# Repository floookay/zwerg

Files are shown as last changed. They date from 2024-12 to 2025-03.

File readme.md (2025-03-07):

# zwerg

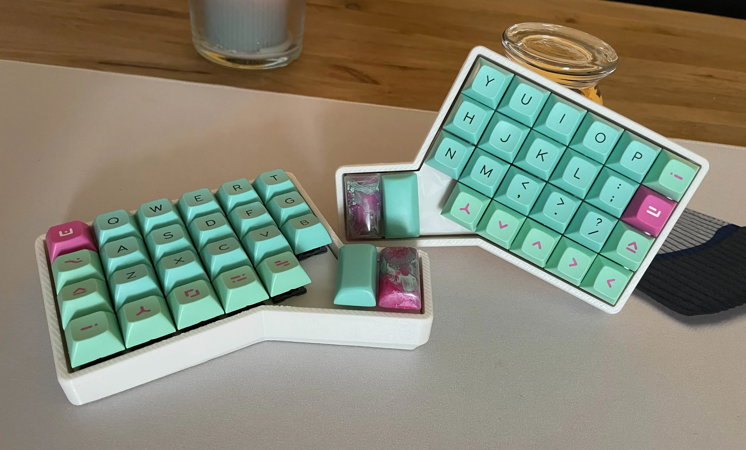
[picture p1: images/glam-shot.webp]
glam shot


The zwerg is a 3x6 (well technically 4x6 I guess?) split ortholinear 40% keyboard.
It's heavily inspired by [RGBKB.net's Sol 3](https://rgbkb.net/collections/sol-3) of which I own two and absolutely adore.

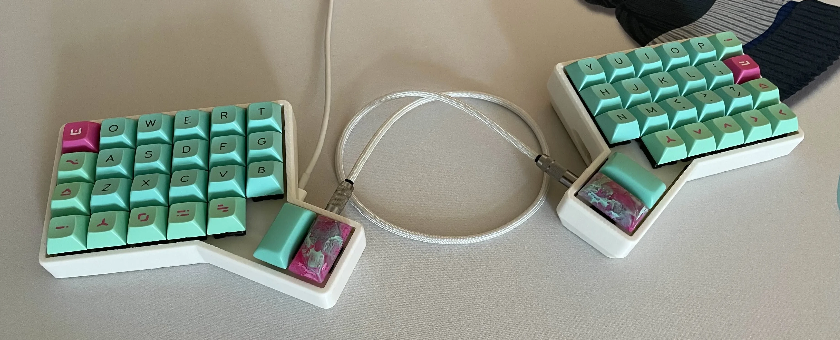
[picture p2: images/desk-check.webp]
desk check
  
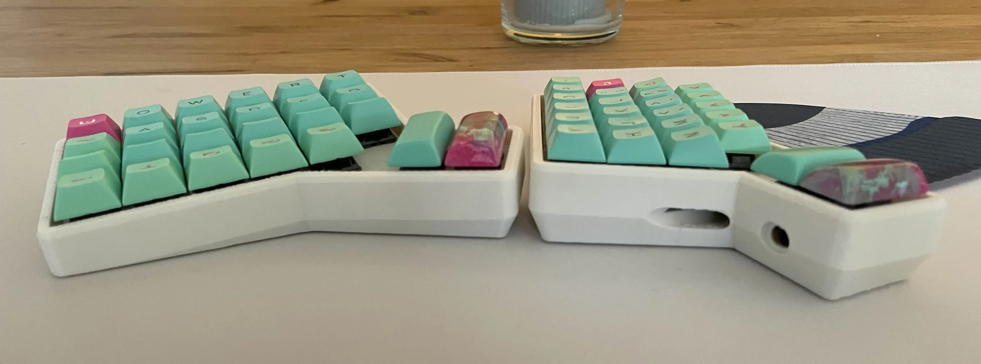
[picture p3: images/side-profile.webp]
side profile


> [!Warning]  
> Please note that this design only works with a slim usb-c cable/connector (5.5mm).

KLE: <https://www.keyboard-layout-editor.com/#/gists/f58560b496cb75689321efaddc96187e>

The typing and tenting angle can be freely adjusted in the OpenSCAD file. I printed mine with a typing angle of 2° and tenting of 5°.

## what you need

- [ ] 2x zwerg pcbs (upload [zwerg.zip](./pcb/production/zwerg.zip) to a pcb manufacturer)
- [ ] 2x [0xCB geminis](https://keeb.supply/products/0xcb-gemini)
- [ ] 50x switches
- [ ] 50x diodes (1N4148W smd or tht)
- [ ] 2x trrs jacks
- [ ] 2x [M2x3x3 heat inserts](https://sea3d.de/10-Stueck-Gewindeeinsatz-M2-Raendelmutter-Einpressmutter-Heat-Set-Insert)
- [ ] 2x M2 5-8mm screws
- [ ] 10x 7x1.9mm o-rings
- [ ] 8x 7x1mm bumpons
- [ ] 2x 3d-printed zwerg case halves (print with supports if needed)
- [ ] *optional* 2x 3d-printed zwerg plates

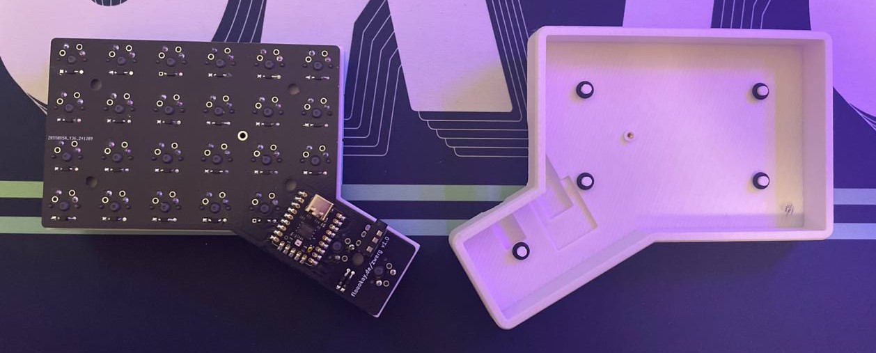
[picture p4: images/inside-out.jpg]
inside out


Building this keyboard is pretty straight forward I think. The only thing you need to look out for is that you solder all components on the same side (same goes for the mirrored pcb). Don't over tighten the screw that attaches the pcb to the case, it's supposed be screwed in lightly.

This keyboard is powered by qmk firmware, see [here](https://github.com/qmk/qmk_firmware/tree/master/keyboards/zwerg). Use the reset buttons on the Gemini for flashing the keyboard.

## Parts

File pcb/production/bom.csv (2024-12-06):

Designator | Footprint | Quantity | Value | LCSC Part #
D1, D10, D11, D12, D13, D14, D15, D16, D17, D18, D19, D2, D20, D21, D22, D23, D24, D25, D3, D4, D5, D6, D7, D8, D9 | D3_TH_SMD | 25 | D_45deg
J1 | CON_MJ-4PP-9_Reversible | 1 | AudioJack4
MX1, MX10, MX11, MX12, MX13, MX14, MX15, MX16, MX17, MX18, MX19, MX2, MX20, MX21, MX22, MX23, MX24, MX25, MX3, MX4, MX5, MX6, MX7, MX8, MX9 | SW_MX_Reversible_1u | 25 | MX_SW_HS

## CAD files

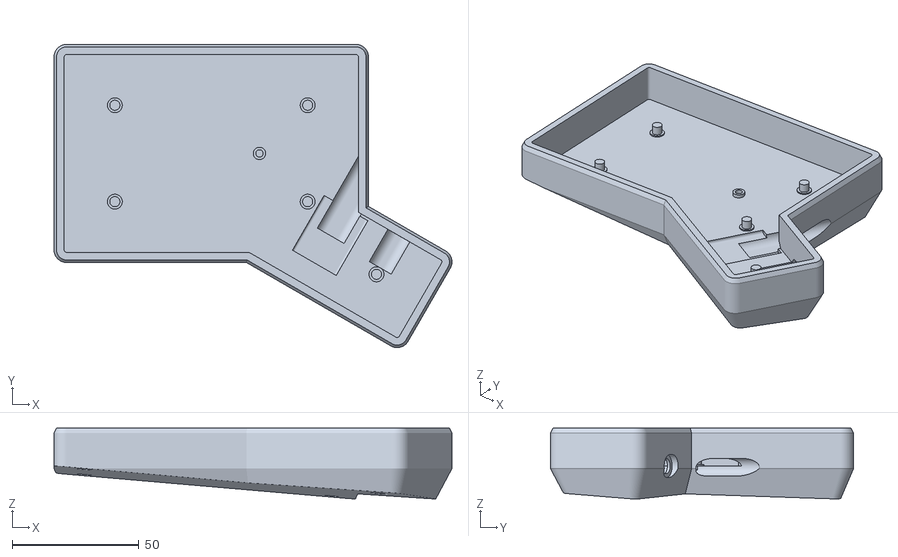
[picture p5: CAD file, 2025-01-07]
case/zwerg.stl
157.3 x 119.8 x 28.0

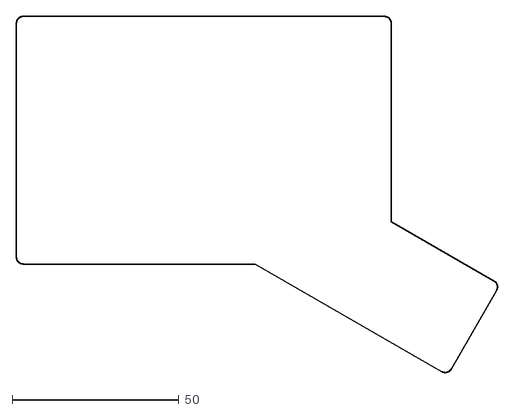
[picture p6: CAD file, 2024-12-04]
pcb/pcb.dxf
144.2 x 106.7

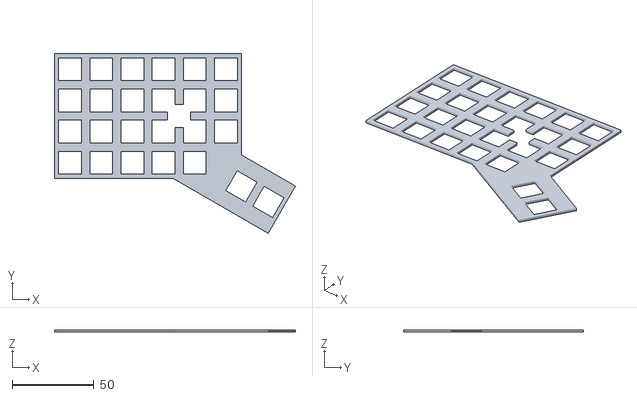
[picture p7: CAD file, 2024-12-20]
case/plate.stl
147.3 x 109.8 x 1.40

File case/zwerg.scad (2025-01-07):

$fn=100;

KEY_UNIT = 19.05;
KEY_HOLE = 14;
KEY_SPACING_CASE = 0.525;
SPACING_INSIDE = 9;
KEY_SPACING = (KEY_UNIT-KEY_HOLE)/2;
ANGLE = 30;
HALF_SPACING = 40;
PLATE_THICKNESS = 1.4;

// case
CASE_CHAMFER = 1;
CASE_RIM_HEIGHT = 6; // 7.8
CASE_RIM_WIDTH = 5;
CASE_BOTTOM_RIM_WIDTH = -10;
CASE_ANGLE = [-2,5,0];    // test with case_height
CASE_HEIGHT = 45;   // test with case_angle

PCB_THICKNESS = 1.6;
PCB_OFFSET = 1;
PCB_HEIGHT_OFFSET = -5;
PCB_CLEARANCE = 2.4;
PCB_PIN = 4;
PCB_PIN_3DP = 4;
PCB_SCREW = 2.2;
PCB_SCREW_3DP = 2.9;
ORING_THICKNESS = 1.9;  // 2.4


BOTTOM_OFFSET = 5;

// for pcb outline and positions
// projection() translate([0,0,-PLATE_THICKNESS]) plate();
// projection() translate([0,0,-PLATE_THICKNESS-5]) pcb();

// translate([0,0,-PLATE_THICKNESS]) plate();
// translate([0,0,-PCB_THICKNESS-5]) color("green") pcb(true);

case();

module case() {
    difference() {
        union() {
            hull() {
                translate([0,0,-SPACING_INSIDE]) linear_extrude(CASE_RIM_HEIGHT+SPACING_INSIDE) offset(CASE_RIM_WIDTH-CASE_CHAMFER) projection() plate_main(solid=true);
                translate([0,0,-SPACING_INSIDE-CASE_CHAMFER]) linear_extrude(CASE_RIM_HEIGHT+SPACING_INSIDE-CASE_CHAMFER) offset(CASE_RIM_WIDTH) projection() plate_main(solid=true);
                translate([0,0,-CASE_HEIGHT]) linear_extrude(0.2) offset(CASE_BOTTOM_RIM_WIDTH) projection() plate_main(solid=true);
            }
            hull() {
                translate([0,0,-SPACING_INSIDE]) linear_extrude(CASE_RIM_HEIGHT+SPACING_INSIDE) offset(CASE_RIM_WIDTH-CASE_CHAMFER) projection() plate_thumbs(solid=true);
                translate([0,0,-SPACING_INSIDE-CASE_CHAMFER]) linear_extrude(CASE_RIM_HEIGHT+SPACING_INSIDE-CASE_CHAMFER) offset(CASE_RIM_WIDTH) projection() plate_thumbs(solid=true);
                translate([0,0,-CASE_HEIGHT]) linear_extrude(0.2) offset(CASE_BOTTOM_RIM_WIDTH) projection() plate_thumbs(solid=true);
            }
        }
        translate([-CASE_RIM_WIDTH,0,-SPACING_INSIDE]) rotate(CASE_ANGLE) translate(v = [0,-200,-200]) cube([400,400,200]);
        translate([0,0,-SPACING_INSIDE]) linear_extrude(20) offset() projection() plate_main(solid=true);
        translate([0,0,-SPACING_INSIDE]) linear_extrude(20) offset() projection() plate_thumbs(solid=true);
        translate([0,0,PCB_HEIGHT_OFFSET-PCB_THICKNESS-PCB_CLEARANCE]) translate([4*KEY_UNIT, 2*KEY_UNIT, -2]) cylinder(h=20,r=(PCB_SCREW_3DP)/2);

        // trrs
        translate([6*KEY_UNIT, 0.75*KEY_UNIT, 0]) rotate([0,0,-ANGLE]) translate([1*KEY_UNIT,-0.5*KEY_UNIT,0])
        translate([0,0,-(PCB_CLEARANCE+PCB_THICKNESS-PCB_HEIGHT_OFFSET)]) rotate([-90,0,0]) translate([-1,0,-4.2]) union() {
            hull() {
                cylinder(h = 30, r = 3);
                translate([2,0,0]) cylinder(h = 30, r = 3);
            }
            hull() {
                cylinder(h = 14.7, r = 4);
                translate([2,0,0]) cylinder(h = 14.7, r = 4);
            }
            translate(v = [0,0,16]) hull() {
                cylinder(h = 30, r = 4.5);
                translate([2,0,0]) cylinder(h = 30, r = 4.5);
            }
        }

        // rp2040
        translate([6*KEY_UNIT, 0.75*KEY_UNIT, 0]) rotate([0,0,-ANGLE]) translate([-6,-0.5*KEY_UNIT,0])
        translate([0,0,-(PCB_CLEARANCE+PCB_THICKNESS-PCB_HEIGHT_OFFSET)]) rotate([-90,0,0]) union() {
            translate([1.5,-1,-3]) cube_rounded([20,5,25],r=1,center=true);
            translate([-1,0.5,-3]) hull() {
                cylinder(h = 100, r = 3.5);
                translate([5.5,0,0]) cylinder(h = 100, r = 3.5);
            }
        }

        // feet
        translate([0,0,-SPACING_INSIDE]) rotate(CASE_ANGLE) translate(v = [0,0,-4.5]) union() {
            translate(v = [7,7,0]) cylinder(h = 5, r = 3.5);
            translate(v = [7,3.6*KEY_UNIT,0]) cylinder(h = 5, r = 3.5);
            translate(v = [6.5*KEY_UNIT,-11,0]) cylinder(h = 5, r = 3.5);
            translate(v = [5.5*KEY_UNIT,3.5*KEY_UNIT,0]) cylinder(h = 5, r = 3.5);
        }
    }
    // pins
    translate([0,0,PCB_HEIGHT_OFFSET-PCB_THICKNESS-PCB_CLEARANCE]) union() {
        translate([1*KEY_UNIT, 1*KEY_UNIT, 0]) union() {
            cylinder(h=PCB_CLEARANCE-ORING_THICKNESS,r=PCB_PIN/2+ORING_THICKNESS/2);
            cylinder(h=PCB_THICKNESS+PCB_CLEARANCE,r=PCB_PIN_3DP/2);
        }
        translate([1*KEY_UNIT, 3*KEY_UNIT, 0]) union() {
            cylinder(h=PCB_CLEARANCE-ORING_THICKNESS,r=PCB_PIN/2+ORING_THICKNESS/2);
            cylinder(h=PCB_THICKNESS+PCB_CLEARANCE,r=PCB_PIN_3DP/2);
        }
        translate([5*KEY_UNIT, 1*KEY_UNIT, 0]) union() {
            cylinder(h=PCB_CLEARANCE-ORING_THICKNESS,r=PCB_PIN/2+ORING_THICKNESS/2);
            cylinder(h=PCB_THICKNESS+PCB_CLEARANCE,r=PCB_PIN_3DP/2);
        }
        translate([5*KEY_UNIT, 3*KEY_UNIT, 0]) union() {
            cylinder(h=PCB_CLEARANCE-ORING_THICKNESS,r=PCB_PIN/2+ORING_THICKNESS/2);
            cylinder(h=PCB_THICKNESS+PCB_CLEARANCE,r=PCB_PIN_3DP/2);
        }

        translate([6*KEY_UNIT, 0.75*KEY_UNIT, 0])
        rotate([0,0,-ANGLE]) translate([-2*KEY_UNIT,-1.75*KEY_UNIT,0]) union() {
            translate([3*KEY_UNIT, 1.75*KEY_UNIT/2, 0]) union() {
                cylinder(h=PCB_CLEARANCE-ORING_THICKNESS,r=PCB_PIN/2+ORING_THICKNESS/2);
                cylinder(h=PCB_THICKNESS+PCB_CLEARANCE,r=PCB_PIN_3DP/2);
            }
        }

        difference() {
            translate([4*KEY_UNIT, 2*KEY_UNIT, 0]) cylinder(h=PCB_CLEARANCE-1,r=(PCB_SCREW_3DP+2)/2);
            translate([4*KEY_UNIT, 2*KEY_UNIT, -2]) cylinder(h=20,r=(PCB_SCREW_3DP)/2);
        }
    }
}

module plate_main(solid=false) {
    difference() {
        cube([6*KEY_UNIT,4*KEY_UNIT,PLATE_THICKNESS]);
        if(!solid)
        {
            for(i=[0:5]) {
                for(j=[0:3]) {
                    if(j != 0 || i != 5)
                    {
                        translate([i*KEY_UNIT,j*KEY_UNIT,0]) hole();
                    }
                }
            }
        }
        translate([5.5*KEY_UNIT,0,-1]) cube([KEY_UNIT/2,KEY_UNIT/2,PLATE_THICKNESS+2]);
    }
}
module plate_thumbs(solid=false) {
    difference() {
        translate([6*KEY_UNIT, 0.75*KEY_UNIT, 0])
        rotate([0,0,-ANGLE]) translate([-2*KEY_UNIT,-1.75*KEY_UNIT,0]) cube([4*KEY_UNIT,1.75*KEY_UNIT,PLATE_THICKNESS]);
        if(!solid)
        {
            difference() {
                translate([0,0,-1]) cube([6*KEY_UNIT,4*KEY_UNIT,PLATE_THICKNESS+2]);
                translate([5.5*KEY_UNIT,0,-2]) cube([KEY_UNIT/2,KEY_UNIT/2,PLATE_THICKNESS+4]);
            }
            translate([6*KEY_UNIT, 0.75*KEY_UNIT, 0])
            rotate([0,0,-ANGLE]) translate([-2*KEY_UNIT,-1.75*KEY_UNIT,0]) union() {
                translate([2*KEY_UNIT,0.75*KEY_UNIT/2,0]) hole();
                translate([3*KEY_UNIT,0.75*KEY_UNIT/2,0]) hole();
            }
        }
    }
}

module plate() {
    difference() {
        union() {
            plate_main();
            plate_thumbs();
        }
        translate([3.5*KEY_UNIT, 1.5*KEY_UNIT,0]) hole();
    }
}
module hole() {
   translate([KEY_SPACING,KEY_SPACING,-1]) cube([KEY_HOLE,KEY_HOLE,PLATE_THICKNESS+2]);
}

module pcb(cutouts = false) {
    difference() {
        union() {
            translate([PCB_OFFSET,PCB_OFFSET,0]) cube_rounded([6*KEY_UNIT-2*PCB_OFFSET,4*KEY_UNIT-2*PCB_OFFSET,PCB_THICKNESS]);
            // translate([6*KEY_UNIT, 0.75*KEY_UNIT, 0]) rotate([0,0,-ANGLE]) translate([-2*KEY_UNIT+PCB_OFFSET,-1.75*KEY_UNIT+PCB_OFFSET,0]) cube_rounded([4*KEY_UNIT-2*PCB_OFFSET,1.75*KEY_UNIT-2*PCB_OFFSET,PCB_THICKNESS]);
            translate([6*KEY_UNIT, 0.75*KEY_UNIT, 0]) rotate([0,0,-ANGLE])
            translate([-2*KEY_UNIT+PCB_OFFSET,-1.75*KEY_UNIT+PCB_OFFSET,0])
            translate([0,(1.75-1.75)*KEY_UNIT/2,0])
            cube_rounded([4*KEY_UNIT-2*PCB_OFFSET,1.75*KEY_UNIT-2*PCB_OFFSET,PCB_THICKNESS]);
        }
        translate([1*KEY_UNIT, 1*KEY_UNIT, -1]) cylinder(h=20,r=PCB_PIN/2);
        translate([1*KEY_UNIT, 3*KEY_UNIT, -1]) cylinder(h=20,r=PCB_PIN/2);
        translate([5*KEY_UNIT, 1*KEY_UNIT, -1]) cylinder(h=20,r=PCB_PIN/2);
        translate([5*KEY_UNIT, 3*KEY_UNIT, -1]) cylinder(h=20,r=PCB_PIN/2);
        translate([4*KEY_UNIT, 2*KEY_UNIT, -1]) cylinder(h=20,r=PCB_SCREW/2);

        translate([6*KEY_UNIT, 0.75*KEY_UNIT, 0])
        rotate([0,0,-ANGLE]) translate([-2*KEY_UNIT,-1.75*KEY_UNIT,0]) union() {
            translate([3*KEY_UNIT, 1.75*KEY_UNIT/2, -1]) cylinder(h=20,r=PCB_PIN/2);
        }
    }
}
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

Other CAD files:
case/plate.dxf

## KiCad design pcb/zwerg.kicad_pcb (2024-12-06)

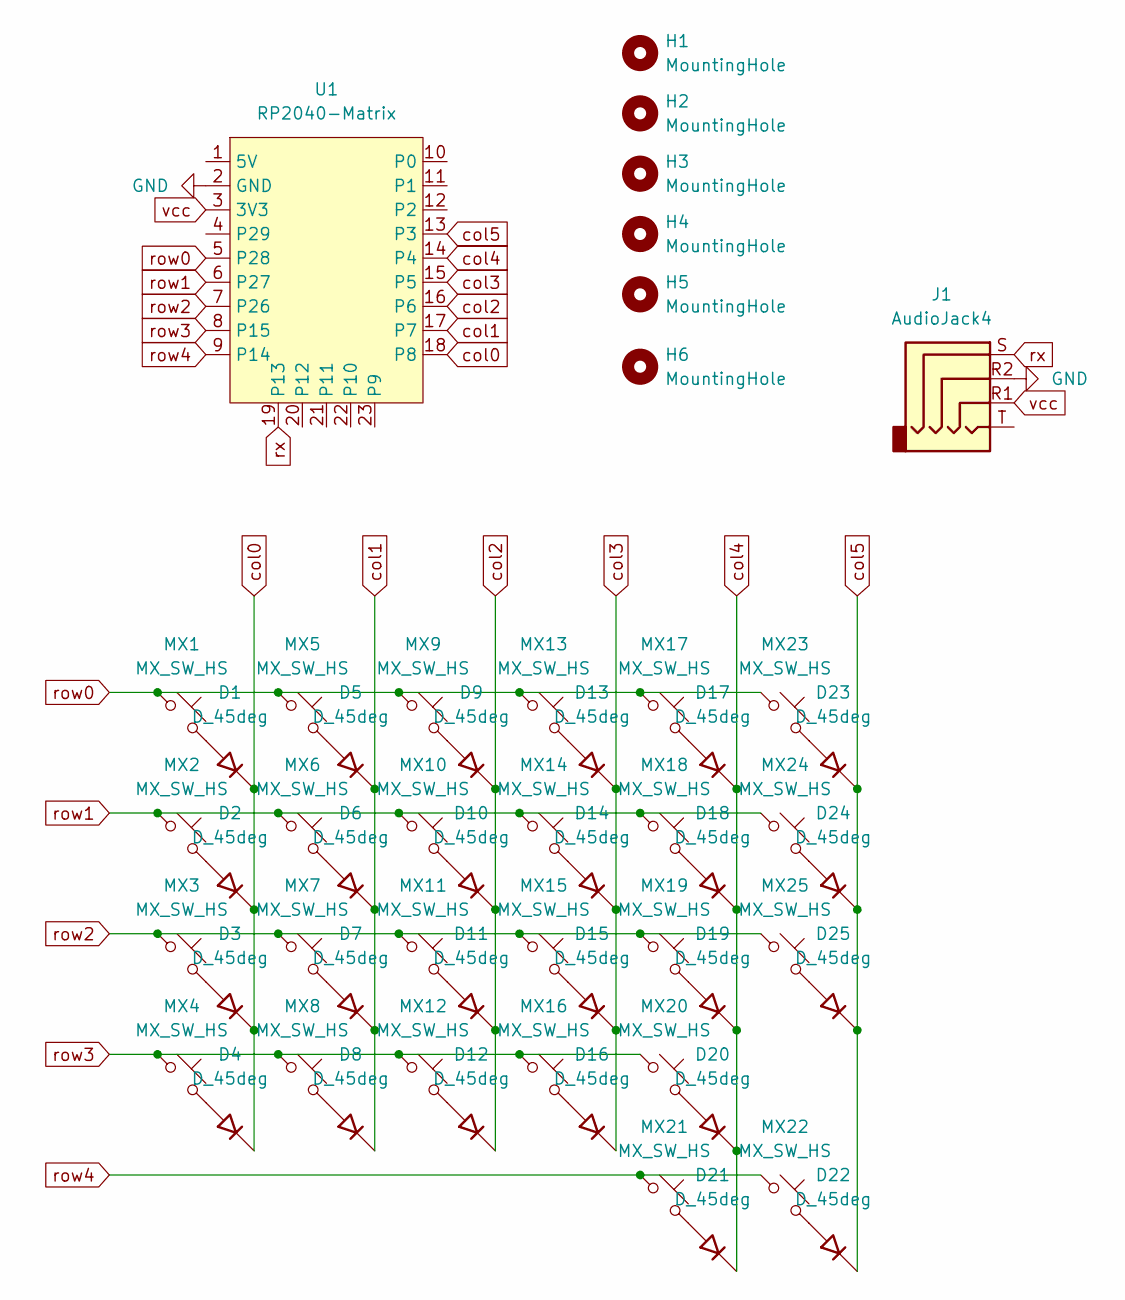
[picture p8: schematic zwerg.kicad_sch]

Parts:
D1, D2, D3, D4, D5, D6, D7, D8, D9, D10, D11, D12, D13, D14, D15, D16, D17, D18, D19, D20, D21, D22, D23, D24, D25: D_45deg; D3_TH_SMD
H1, H2, H3, H4, H5: MountingHole; MountingHole_4.3mm_M4
H6: MountingHole; MountingHole_2.2mm_M2_DIN965_Pad_TopBottom
J1: AudioJack4; CON_MJ-4PP-9_Reversible
MX1, MX2, MX3, MX4, MX5, MX6, MX7, MX8, MX9, MX10, MX11, MX12, MX13, MX14, MX15, MX16, MX17, MX18, MX19, MX20, MX21, MX22, MX23, MX24, MX25: MX_SW_HS; SW_MX_Reversible_1u
U1: RP2040-Matrix; RP2040-Matrix_fb

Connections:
GND: J1.R2, U1.2 (GND)
unnamed: D1.2 (A), MX1.2
unnamed: D2.2 (A), MX2.2
unnamed: D3.2 (A), MX3.2
unnamed: D4.2 (A), MX4.2
unnamed: D5.2 (A), MX5.2
unnamed: D6.2 (A), MX6.2
unnamed: D7.2 (A), MX7.2
unnamed: D8.2 (A), MX8.2
unnamed: D9.2 (A), MX9.2
unnamed: D10.2 (A), MX10.2
unnamed: D11.2 (A), MX11.2
unnamed: D12.2 (A), MX12.2
unnamed: D13.2 (A), MX13.2
unnamed: D14.2 (A), MX14.2
unnamed: D15.2 (A), MX15.2
unnamed: D16.2 (A), MX16.2
unnamed: D17.2 (A), MX17.2
unnamed: D18.2 (A), MX18.2
unnamed: D19.2 (A), MX19.2
unnamed: D20.2 (A), MX20.2
unnamed: D21.2 (A), MX21.2
unnamed: D22.2 (A), MX22.2
unnamed: D23.2 (A), MX23.2
unnamed: D24.2 (A), MX24.2
unnamed: D25.2 (A), MX25.2
col0: D1.1 (K), D2.1 (K), D3.1 (K), D4.1 (K), U1.18 (P8)
col1: D5.1 (K), D6.1 (K), D7.1 (K), D8.1 (K), U1.17 (P7)
col2: D9.1 (K), D10.1 (K), D11.1 (K), D12.1 (K), U1.16 (P6)
col3: D13.1 (K), D14.1 (K), D15.1 (K), D16.1 (K), U1.15 (P5)
col4: D17.1 (K), D18.1 (K), D19.1 (K), D20.1 (K), D21.1 (K), U1.14 (P4)
col5: D22.1 (K), D23.1 (K), D24.1 (K), D25.1 (K), U1.13 (P3)
row0: MX1.1, MX5.1, MX9.1, MX13.1, MX17.1, MX23.1, U1.5 (P28)
row1: MX2.1, MX6.1, MX10.1, MX14.1, MX18.1, MX24.1, U1.6 (P27)
row2: MX3.1, MX7.1, MX11.1, MX15.1, MX19.1, MX25.1, U1.7 (P26)
row3: MX4.1, MX8.1, MX12.1, MX16.1, MX20.1, U1.8 (P15)
row4: MX21.1, MX22.1, U1.9 (P14)
rx: J1.S, U1.19 (P13)
vcc: J1.R1, U1.3 (3V3)

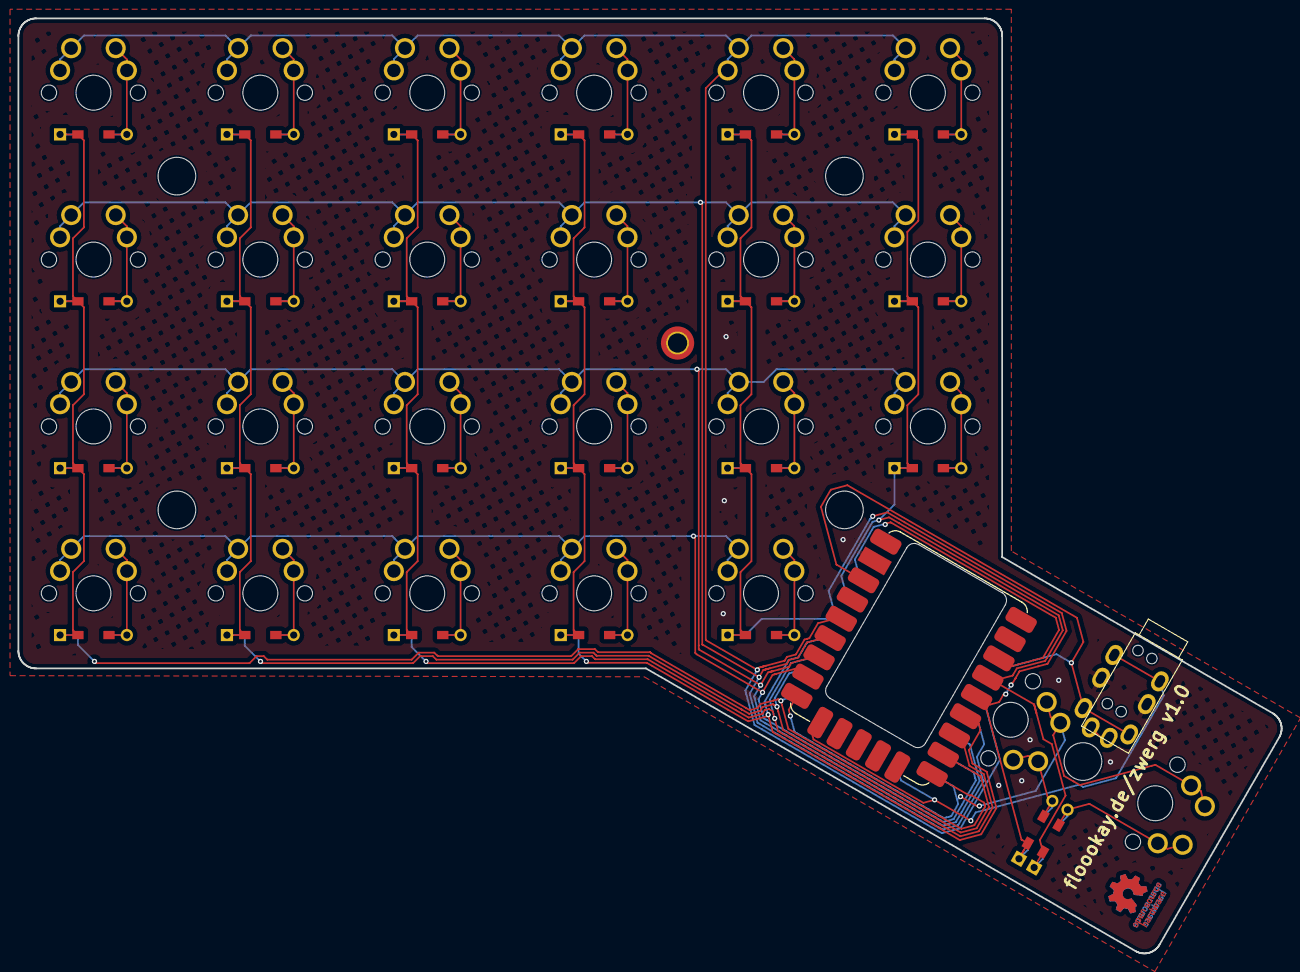
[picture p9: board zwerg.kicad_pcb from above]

Board: 2 copper layers, 144.2 x 106.7 mm, 58 parts (0 on the bottom side), 39 nets.

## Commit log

2024-11-30 added case files
    [pcb.dxf, plate.dxf, plate.stl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]
2024-12-04 added pcb draft
    [pcb.dxf, zwerg.kicad_pcb, zwerg.kicad_sch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]
2024-12-06 updated pcb and case v1.0
    [bom.csv, designators.csv, positions.csv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]
2024-12-20 increased clearance and added screw hole to plate
    [plate.stl, zwerg.scad, zwerg.stl]
2025-01-07 added feet and opening for trrs connector
    [zwerg.scad, zwerg.stl]
2025-01-07 shrinked usbc hole stlightly
    [zwerg.scad, zwerg.stl]
